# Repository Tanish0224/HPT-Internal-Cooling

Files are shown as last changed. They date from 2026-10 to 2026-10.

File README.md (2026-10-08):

# Cooled HPT Blade: Cooling Architecture and CAD

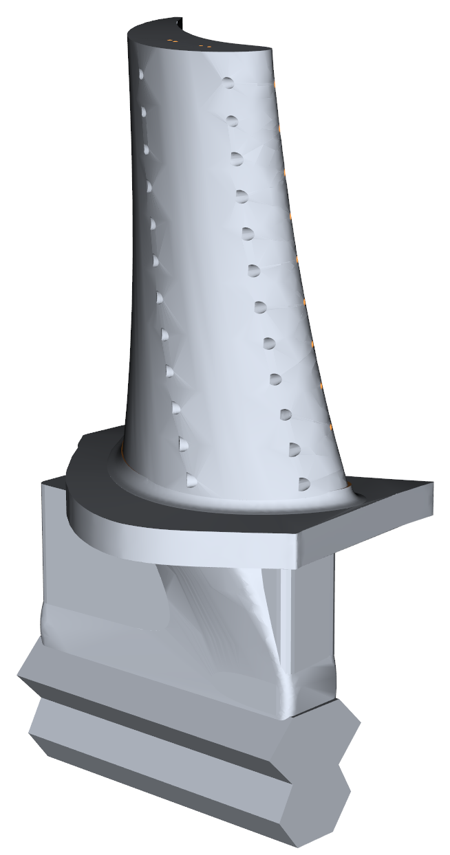
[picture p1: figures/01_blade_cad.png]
Current HPT blade CAD


A high-pressure-turbine (HPT) rotor blade with a two-circuit internal cooling system and film cooling, modelled as a
single CAD solid (66-blade stage, 45 mm span). The repository contains the current CAD model together with its design
basis, the reasoning behind the cooling architecture, and a review of the exported geometry. The project focuses on CAD
design and cooling-architecture development; no CFD, conjugate heat-transfer or structural analysis has been run on the
current CAD model.

## The engineering problem

The first rotor blade of an HPT sits in gas hotter than its nickel single-crystal alloy can tolerate. At the assumed
rotor-inlet condition the blade sees a relative total temperature of about 1,590 K, while the metal has to stay near
1,357 K locally and 1,226 K in bulk to reach a useful creep life. The gap is closed with compressor air routed through
the blade. That air does no work in the blade row and adds mixing loss where it re-enters the gas path, so the design
question is how to hold the metal limits with the least coolant, in a blade that can be cast and drilled.

## Design objective

Develop a turbine-blade CAD model that incorporates a practical cooling architecture: internal cooling to remove heat
from the wall, and film cooling to lower the temperature of the gas that drives heat into it, with coolant fed from the
root and discharged where its pressure suits the local external pressure.

## Cooling architecture

Two internal coolant circuits are fed separately at the root face and exit where their pressure suits them.

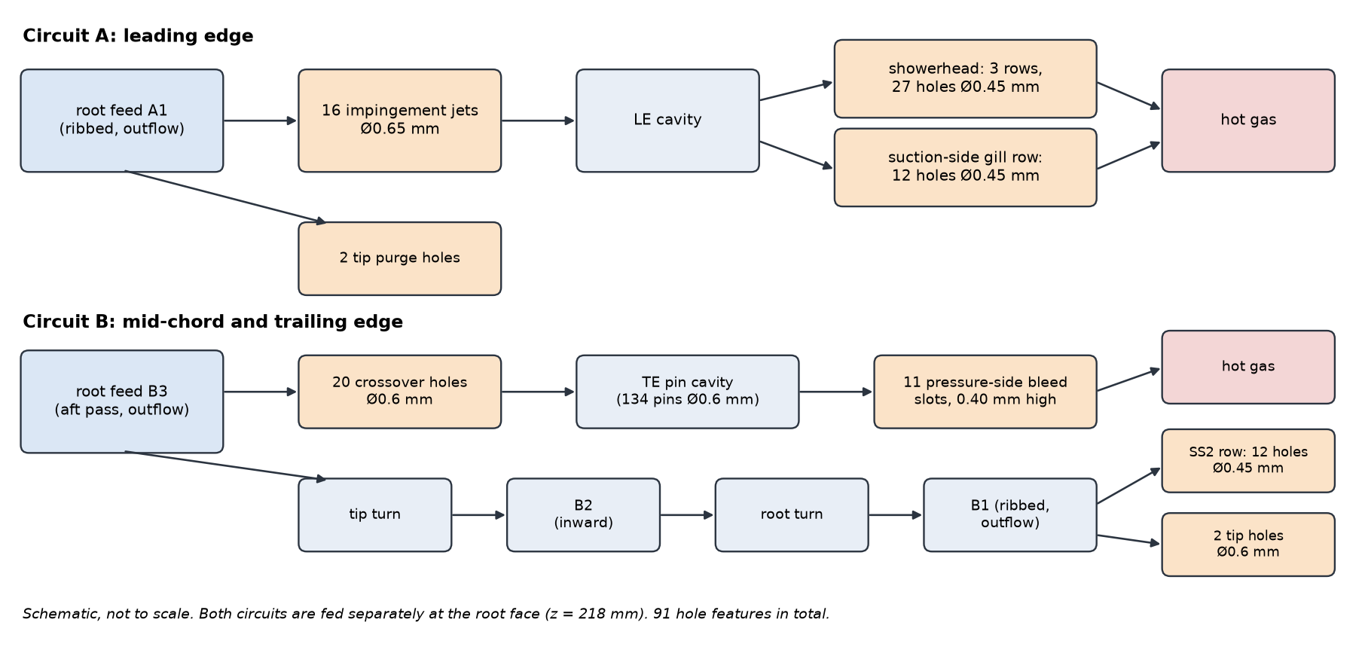
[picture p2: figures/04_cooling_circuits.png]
Coolant circuits


* **Circuit A, leading edge.** Root feed A1 supplies 16 impingement jets that strike the inside of the leading-edge
  cavity; the spent air leaves through three rows of showerhead holes and a suction-side film row.
* **Circuit B, mid-chord and trailing edge.** The aft passage B3 feeds the trailing-edge pin cavity, which discharges
  through 11 pressure-side bleed slots. The rest of the flow runs a three-pass ribbed serpentine (B3, B2, B1) and leaves
  through a second suction-side film row and tip holes.

The model contains 91 hole features (16 impingement jets, 20 trailing-edge crossover holes, 27 showerhead holes, 12 + 12
suction-side film holes and 4 tip holes), 70 rib segments, 134 trailing-edge pins and 11 discharge slots.

## Design basis

The geometry was developed from an assumed stage operating point anchored to published GE test-engine data. Values taken
from the published reference are separated from project assumptions in the status column.

| | Value | Status |
|---|---|---|
| Rotor-inlet gas | 1,700 K, 3.0 MPa; nozzle exit 600 m/s at 68° | ASSUMED, anchored to the NASA/GE Energy Efficient Engine HPT (rotor inlet 1,694 K) |
| Blade speed | 350 m/s at 275 mm mean radius (12,154 rpm) | ASSUMED |
| Stage | 66 blades, span 45 mm (252.5–297.5 mm radius), exit swirl −20° | Reaction 0.20 hub, 0.32 mean |
| Sections | thickness/chord 0.21 hub, 0.19 mean, 0.17 tip; leading-edge radius 1.8 mm | Sized to fit six cavities |
| Coolant at the root | 879 K, 2.95 MPa; target about 3 % of core flow | CALCULATED from the reference engine's cooling source, with an assumed supply loss |
| Metal limits | 1,357 K local, 1,226 K bulk | ASSUMED, anchored to the reference engine's coating and pitch-line temperatures |
| Walls | 1.0 mm skin, 0.9 mm webs, 0.75 mm trailing-edge lip | DECISION; no manufacturing source (see [limitations](LIMITATIONS.md)) |

Details, sources and the decision list are in [`design/`](design/README.md).

## Why the main features exist

| Feature | Reason |
|---|---|
| Two circuits fed from the root | The showerhead exits at near-stagnation pressure and the trailing edge at the lowest, so each circuit has its own supply. The two-circuit design has a showerhead back-flow margin of 0.11 (CALCULATED, 94-hole model); a shared-supply case was not calculated |
| Impingement jets in the leading edge | Highest external heat transfer is at the stagnation region; the jets give the nose its internal cooling |
| Three-pass ribbed serpentine | A two-pass layout with large passages warmed the coolant only 60–80 K; smaller passages and three passes raised the exit temperature to about 970 K at about 3 % flow |
| Trailing edge fed from the first pass | The coolest air goes to the thinnest, hardest-to-cool region, as in the reference engine |
| Pin cavity and 11 bleed slots | The thin trailing edge needs pins for conduction and heat transfer; the slot count follows the reference engine |
| Two suction-side film rows, no pressure-side row | The model put the peak metal temperature on the mid suction side; a pressure-side row over-cooled that surface and starved the serpentine |
| Film holes not smaller than 0.45 mm | The optimiser drove holes to 0.35 mm; the reference design used 0.51 mm and notes that small holes plug |
| Flared shank | Puts the airfoil walls over the shank instead of loading the platform in bending (earlier-geometry screening FEA: hub-band peak von Mises 942 → 593 MPa) |

*Rows that quote model outcomes (coolant warm-up, over-cooling, hole size) come from the project's coupled model on an earlier geometry; those data are not published, and [figure 05](figures/05_design_iterations.png) shows the iteration chart.*

## Current CAD model

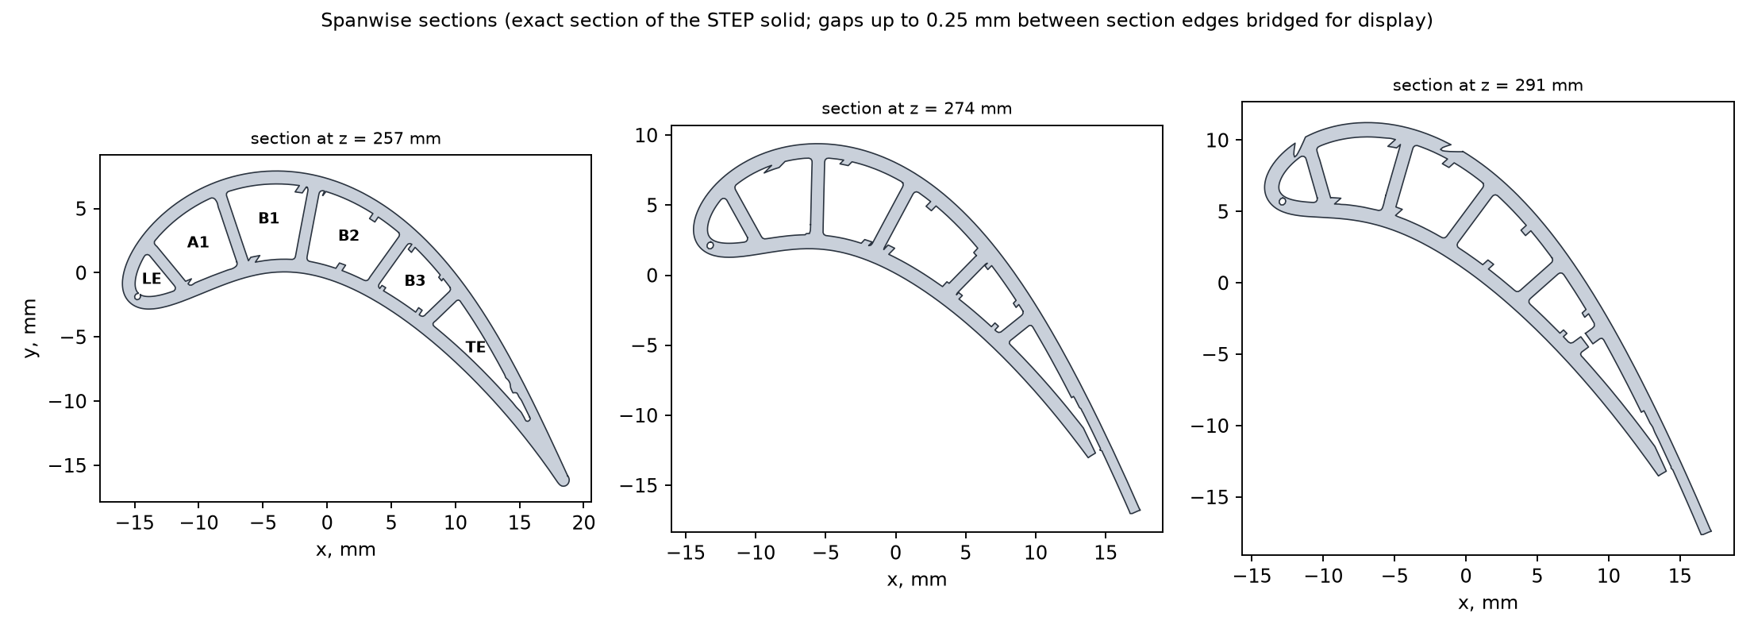
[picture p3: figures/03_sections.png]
Sections


*Sections of the exported solid (gaps up to 0.25 mm between section edges are bridged for display). At z = 257 mm the six
passages are labelled; at the higher stations the plane crosses hole and slot cuts, which open some passages to the outside.*

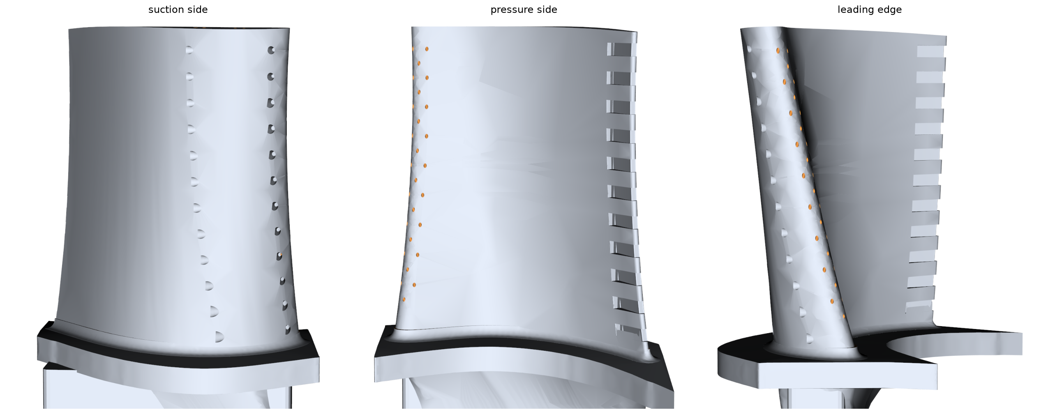
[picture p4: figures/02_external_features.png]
External features


The blade is one valid solid of 1,542 faces and 17,216.6 mm³, with the root face at z = 218 mm and the airfoil tip at
z = 297.5 mm. The cooling design file listed 94 holes; three were removed because their geometry was unsound (two showerhead
holes ended in a dead-end tail and the last trailing-edge crossover hole overlapped the tip turn), leaving the 91 above
([why](design/README.md#from-94-to-91-hole-features)). The CAD files, their identification hashes and the coordinate
system are described in [`cad/`](cad/README.md).

## Key results

The current CAD model is a single valid blade solid with 1,542 faces and 17,216.6 mm³ volume. All 91 cooling-hole openings and 11 trailing-edge discharge slots were confirmed on the exported geometry, with sampled wall thickness of at least 0.68 mm.
The design allocates 3.15% of core flow to coolant, and the project thermal model predicts a peak metal temperature of 1,317 K, 40 K below the assumed local limit; this is not a CFD result.

## Repository map

| | |
|---|---|
| [`design/`](design/README.md) | operating point, architecture, decisions and why, sensitivities, references |
| [`cad/`](cad/README.md) | the current CAD model (zipped STEP), structural derivative, identification, how to open it |
| [`verification/`](verification/README.md) | geometry review of the exported CAD, with recorded results |
| [`data/`](data/) | design data: section definition, design basis, cooling design |
| [`analysis_context/`](analysis_context/README.md) | 2-D RANS and FEA on earlier geometry; not validation of the current CAD |
| [`history/`](history/README.md) | the initial design and how the design evolved, briefly |
| [`scripts/`](scripts/README.md) | design-basis calculation, panel method and wall-thickness measurement |
| [`EVIDENCE_INDEX.md`](EVIDENCE_INDEX.md) | where each number comes from |
| [`figures/`](figures/README.md) | figures and their sources |

This repository has not undergone independent external review.

Project by **Tanish Shetty**. Tools: Python (NumPy) for design calculations, SolidWorks 2026
(import and volume comparison), ANSYS Fluent 2025 R1 and ANSYS MAPDL 2025 R1 (earlier geometry only). Code is MIT-licensed; CAD and figures
are covered by [`ASSET_NOTICE.md`](ASSET_NOTICE.md).

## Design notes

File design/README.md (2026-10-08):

# Design basis and cooling architecture

Labels used throughout (**SIMULATION**: CFD or FEA, earlier geometry only; results marked "model output, not published" come from the project model, whose data are not in this repository): **SOURCED** (taken from a cited public document), **ASSUMED** (a project assumption),
**CALCULATED** (derived by the project's models), **DECISION** (a design choice), **VERIFIED** (measured on the CAD).

## The thermal problem

The first rotor blade of a high-pressure turbine sits in gas hotter than its nickel single-crystal alloy can tolerate.
At the assumed rotor-inlet condition the blade sees a relative total temperature of about 1,590 K, while the metal has
to stay near 1,357 K locally and 1,226 K in bulk to reach a useful creep life. The gap is closed with air taken
from the compressor and routed through the blade. That air is not free: it bypasses the combustor, does no work in
the blade row and adds mixing loss where it re-enters the gas path. The design question is how to hold the metal limits
with the least coolant, in a blade that can be cast and drilled.

Internal cooling (impingement, ribbed passages, pins) removes heat from the wall; film cooling lowers the temperature of
the gas that drives heat into it. Neither is sufficient alone where the external heat load is highest, and the
pressure that drives the coolant out must exceed the local external pressure with margin at every exit.

## Operating point and blade basis

| Quantity | Value | Status |
|---|---|---|
| Rotor-inlet T01, P01 | 1,700 K, 3.0 MPa | ASSUMED; reference engine rotor-inlet design 1,421 °C = 1,694 K, compressor delivery 2.66–3.08 MPa (SOURCED, [G1](REFERENCES.md)) |
| Nozzle exit | 600 m/s at 68° | ASSUMED |
| Blade speed | 350 m/s at the 275 mm mean radius (12,154 rpm) | ASSUMED |
| Annulus | radius 252.5–297.5 mm (span 45 mm) | retained from an earlier project stage |
| Rotor exit swirl | −20° | DECISION: hub reaction about 0.2 (0.196); mean reaction 0.32 (reference engine 0.34) |
| Core flow | 79.9 kg/s, 1.21 kg/s per blade passage | CALCULATED |
| Blades | 66 | DECISION; suction-side diffusion ratio 1.17–1.20 for 66–72 blades, Zweifel about 1.0 |
| Sections | thickness/chord 0.21 / 0.19 / 0.17 (hub / mean / tip), leading-edge radius 1.8 mm | DECISION, the smallest values that hold six cavities with 1.0 mm walls and 0.9 mm webs |
| Chord | 38.9 / 38.6 / 41.5 mm | CALCULATED from the section definition ([`../data/blade_sections.json`](../data/blade_sections.json)) |
| Stacking lean | 1.06 mm axial, 2.22 mm tangential at the tip | CALCULATED; cancels design-point gas bending (hub bending stress 102 → about 0 MPa) |
| Coolant at the root | 879 K, 2.95 MPa | CALCULATED from the reference engine's cooling-air source (593 °C), an assumed inducer radius of 0.15 m and a 5 % supply loss |
| Coolant target | about 3 % of core flow | ASSUMED, within the reference blade's 2.25–3.3 % |
| Metal limits | 1,357 K local, 1,226 K bulk | ANCHORED to the reference blade's coating maximum (1,084 °C) and pitch-line bulk temperature (953 °C) |
| Alloy | CMSX-4-class single crystal, ⟨001⟩ radial | DECISION; properties ASSUMED |

Velocity triangles (free vortex, constant axial velocity 225 m/s):

| | exit angle β3 | turning | ψ = Δh/U² | reaction | M3,rel |
|---|---|---|---|---|---|
| hub | −61.3° | 113.0° | 2.16 | 0.20 | 0.63 |
| mean | −62.5° | 105.1° | 1.82 | 0.32 | 0.65 |
| tip | −63.7° | 94.8° | 1.56 | 0.42 | 0.68 |

The stage is more highly loaded than the reference engine (tip speed 379 m/s against 514 m/s), which is ASSUMED to lie
within high-work HPT practice; centrifugal stresses are correspondingly lower than an engine-scale rotor would see.

## Cooling architecture

Two circuits are fed separately at the root face (z = 218 mm). Each exits where its pressure suits it.

| Family | Count | Diameter / size | Fed by | Role |
|---|---|---|---|---|
| Leading-edge impingement jets | 16 | 0.65 mm | A1 | strike the inside of the leading-edge cavity (s/d = 4) |
| Showerhead | 27 (3 rows) | 0.45 mm, 30° radial | LE cavity | film over the stagnation region |
| Suction-side gill row | 12 | 0.45 mm, shaped, at 6.0 mm from stagnation | LE cavity | film on the accelerating suction side |
| Suction-side second row (SS2) | 12 | 0.45 mm, shaped, at 28 % camber | B1 | film where the model put the peak temperature |
| Trailing-edge crossover | 20 | 0.6 mm | B3 | feed the pin cavity |
| Tip holes | 4 | 2 × 0.45 mm (A1), 2 × 0.6 mm (B1) | A1, B1 | keep dead-ended passages flowing near the tip |
| **Hole features** | **91** | | | |
| Pressure-side bleed slots | 11 | 0.40 mm high, 1.78 mm open, 2.13 mm lands, cut-back at 88 % chord | pin cavity | trailing-edge exit |
| Trailing-edge pins | 134 | 0.6 mm, 1.4 mm pitch | | conduction and heat transfer in the thin trailing edge |
| Ribs | 70 segments | height 0.10 of the hydraulic diameter, pitch 10 × height | A1, B1, B2, B3 | raise internal heat transfer |

Walls are 1.0 mm, webs 0.9 mm, core fillets 0.25 mm and the trailing-edge suction-side lip 0.75 mm (DECISION).

* **Circuit A** (15.9 g/s, 94-hole design): A1 → 16 jets → leading-edge cavity → showerhead and gill row; two tip purge holes.
* **Circuit B** (22.7 g/s, 94-hole design): B3 → crossover holes → pin cavity → 11 bleed slots; B3 → tip turn → B2 → root turn →
  B1 → SS2 row and two tip holes.

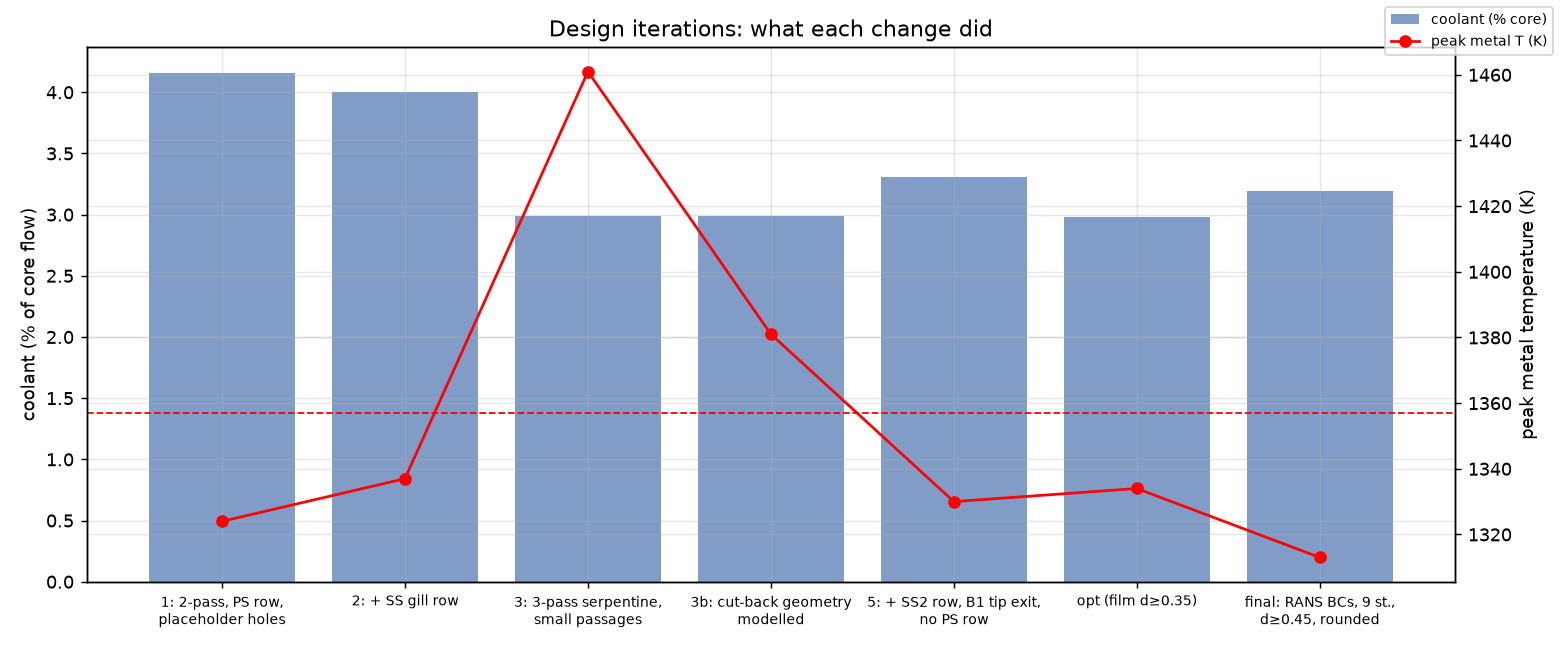
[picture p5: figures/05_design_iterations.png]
Design iterations


*How the architecture came out of the model (CALCULATED, earlier-geometry model): each change and what it did to coolant
fraction and peak metal temperature.*

| Iteration | Change | Coolant | Peak metal | Lesson |
|---|---|---|---|---|
| 1 | two-pass serpentine, pressure-side row, placeholder holes | 4.16 % | 1,324 K | over-cooled; coolant heated only 60–80 K |
| 2 | + suction-side gill row | 4.00 % | 1,337 K | more exit area raised circuit-A flow, not cooling |
| 3 | three-pass serpentine, smaller passages | 2.99 % | 1,461 K | coolant used well; the trailing-edge hot spot was a modelling error |
| 3b | pressure-side cut-back modelled geometrically | 2.99 % | 1,381 K | hot band on the mid suction side over B1 |
| 5 | + SS2 row, B1 tip exit, no pressure-side row | 3.31 % | 1,330 K | pressure side needed no film |
| opt | 15-variable constrained optimisation | 2.98 % | 1,334 K | optimiser pushed holes to 0.35 mm |
| final | external boundary conditions from RANS, holes ≥ 0.45 mm, rounded | 3.19 % | 1,312 K | the chart shows the 1,313 K of the run before the last rounding |

## Coupled model results (CALCULATED, not CFD on this geometry)

The model is a 2-D finite-volume conduction solution in the real metal section at nine radii, coupled to a 1-D coolant
network per circuit (supply pressure, inlet loss, rotation, rib friction, turns, orifices to the local static pressure)
and to a film-effectiveness correlation. External boundary conditions come from 2-D RANS at hub, mean and tip on the
earlier geometry ([`analysis_context/`](../analysis_context/README.md)).

| | Designed, 94 hole features | project model, 91 hole features (as modelled in the current CAD) |
|---|---|---|
| Coolant per blade | 38.6 g/s = 3.19 % of core flow | 38.1 g/s = 3.15 % |
| Peak metal temperature | 1,312 K (suction side near the tip) | 1,317 K |
| Mean section bulk temperature | 1,147 K | 1,151 K |
| Minimum showerhead back-flow margin | 0.112 | not recomputed |

Uncertainty (94-hole model; peak metal temperature, nominal 1,312 K):

| Perturbation | Change |
|---|---|
| film effectiveness −30 % | +46 K |
| cut-back effectiveness 0.7 → 0.5 | +47 K |
| internal heat transfer −20 % | +6 K |
| metal conductivity −15 % / +15 % | +3 / −2 K |
| leading-edge impingement −30 % | −1 K |

The nominal design holds 45 K margin to the local limit; either film uncertainty alone exceeds it (film −30 % gives 1,358 K against the 1,357 K limit). Film behaviour is
therefore the first thing a simulation of the current design should resolve. Raw numbers: [`sensitivity/`](sensitivity/).

## From 94 to 91 hole features

The original design file listed 94 holes. A geometric review of the hole geometry against the cavities found three that were not sound; they were removed from the CAD before the current model was finalised:

| Removed | Geometry problem | Evidence |
|---|---|---|
| showerhead holes #0 and #19 | the 30° radial inclination put the hole's inner end about 3.4 mm hub-ward of the exit, below the leading-edge cavity floor, leaving a 0.8 mm dead-end tail | position of the hole's inner end against the cavity floor |
| trailing-edge crossover #20 | the last station (z = 295 mm) lies inside the tip turn and overlapped it | position of the last station against the tip turn |

Thermal effect, bounded by the model with a smeared hole density: removing the two showerhead holes gives +5.5 K peak
metal temperature and −0.3 g/s coolant; removing the crossover hole gives 0 K and −0.2 g/s (together +5.5 K and −0.5 g/s). This is an analysis
assumption and has not been checked by simulation of the current design.

## Assumptions that carry manufacturing risk

1. The 0.75 mm trailing-edge lip and the 0.40 mm slot need an advanced thin-wall casting process or core-wall control;
   a thicker lip was rejected because it thins the pressure-side wall over the slot (lip thickness 0.75 / 0.80 / 0.85 mm
   changes peak metal temperature by about 0.5 K, [`sensitivity/`](sensitivity/)).
2. Skin and web walls of 0.85–1.0 mm are within what conventional casting is described to reach (above about 0.76 mm,
   US 6,255,000); the thinner values are not.
3. 0.45 mm holes are drilled or EDM-formed after casting.
4. No manufacturer capability, tolerance or yield has been established.

## Files

* [`decisions.md`](decisions.md): the main design decisions and the reason for each.
* [`REFERENCES.md`](REFERENCES.md): sources.
* [`sensitivity/`](sensitivity/): hole-removal, lip-thickness and film/internal-heat-transfer sensitivities.
* [`../data/`](../data/): the design data behind the CAD: `blade_sections.json` (section definition), `design_basis.json` (operating point, velocity triangles, limits) and `cooling_design.json` (passages, hole rows, ribs, pins and slots).

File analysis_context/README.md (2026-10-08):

# Analysis context: 2-D RANS and screening FEA on earlier geometry

> **Earlier geometry. Not validation of the current design.**
> Everything in this folder was run on the second-design blade, not on the current design, and the results are not attached to the current design.
> The current-design CAD has had no CFD, conjugate heat-transfer or structural analysis.

These analyses explain where the design inputs came from: the external boundary conditions of the cooling model and the
structural reasoning behind the shank shape. They are included so the design can be traced, not as evidence for the final CAD.

## 2-D blade-to-blade RANS (external flow)

* **Set-up.** ANSYS Fluent 2025 R1, compressible, k-ω SST, ideal gas (γ = 1.3), periodic blade-to-blade domain at hub, mean
  and tip, y⁺ about 1.3 (maximum 2.0), about 41,000 cells per section. Adiabatic-wall temperature from one run, heat-transfer
  coefficient from an isothermal run (h = q / (T_aw − 1,250 K)).
* **Purpose.** Surface pressure and external heat-transfer distributions as boundary conditions for the cooling model, and a
  check of the panel-method loading used to shape the airfoil.
* **Defect found and corrected.** The first runs used the solver's default energy equation, which omitted viscous dissipation,
  pressure work and kinetic energy; the adiabatic wall then recovered only about 30 % of the dynamic temperature. All runs were
  repeated with the full energy equation, after which the adiabatic-wall temperature matched the analytical recovery
  temperature within a few kelvin.

| | exit angle RANS / design | exit Mach RANS / design | loss Y |
|---|---|---|---|
| hub | −60.7° / −61.3° | 0.612 / 0.626 | 0.050 |
| mean | −62.3° / −62.5° | 0.639 / 0.651 | 0.043 |
| tip | −63.6° / −63.7° | 0.666 / 0.678 | 0.039 |

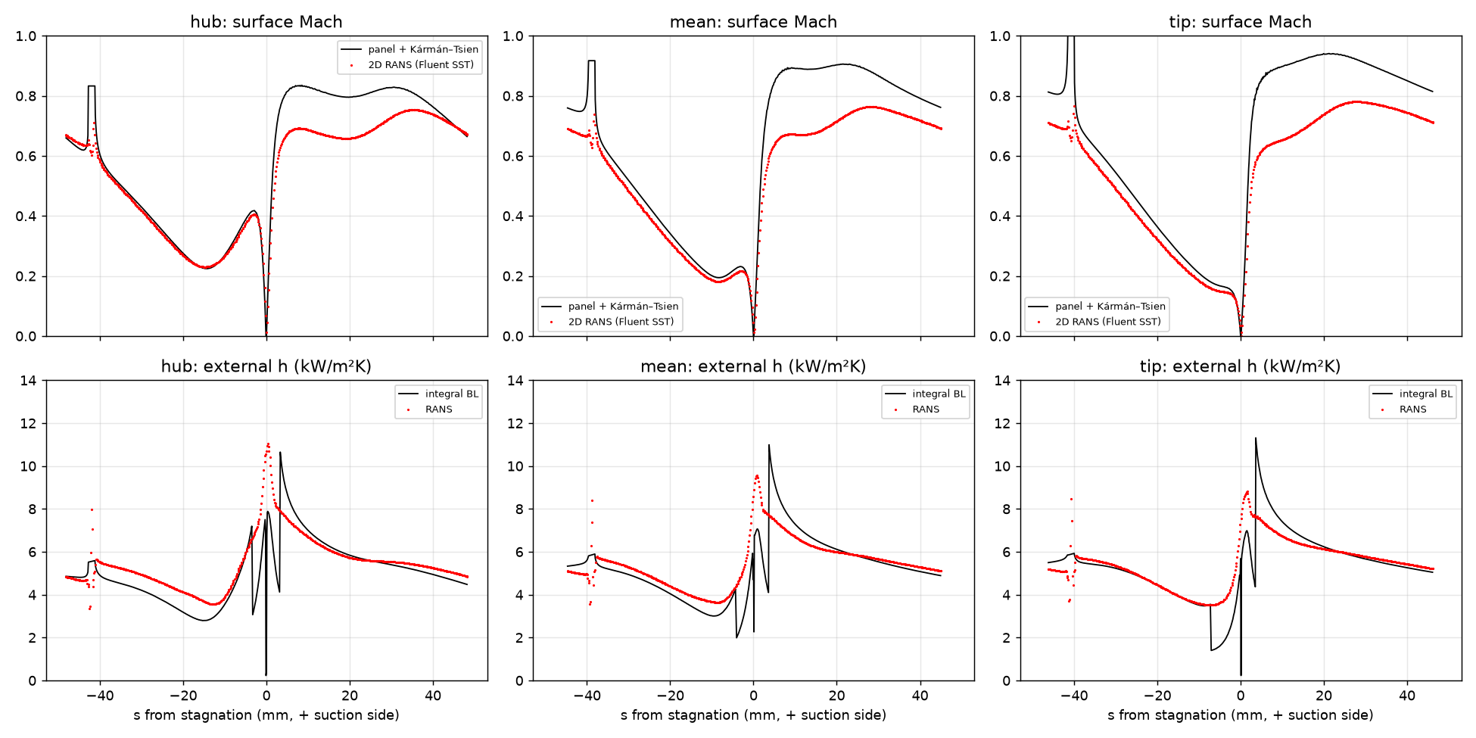
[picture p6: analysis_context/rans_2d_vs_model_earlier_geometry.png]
RANS against the panel and integral models


The panel method predicts the exit angle within 0.6° and overpredicts suction-side peak Mach: RANS peaks at 0.75 / 0.76 / 0.78 (hub / mean / tip; maxima of the stored `M_cfd` data), the panel curves in the figure at about 0.83 / 0.91 / 0.94 (read from the plot; the panel values are not stored in this repository). Section-averaged
external h agrees within 2 % on the suction side between RANS and an integral boundary-layer model; RANS is 9–19 % higher on the
pressure side and at the stagnation point (9.5 against 7 kW/m²K for the mean section). The design uses the RANS distributions, the more
conservative of the two. Data: [`rans_2d/`](rans_2d/).

Limits: two-dimensional, no tip gap, endwall or film-hole flow, no conjugate heat transfer, one turbulence model, no mesh study reported.

## Metal temperature (project model)

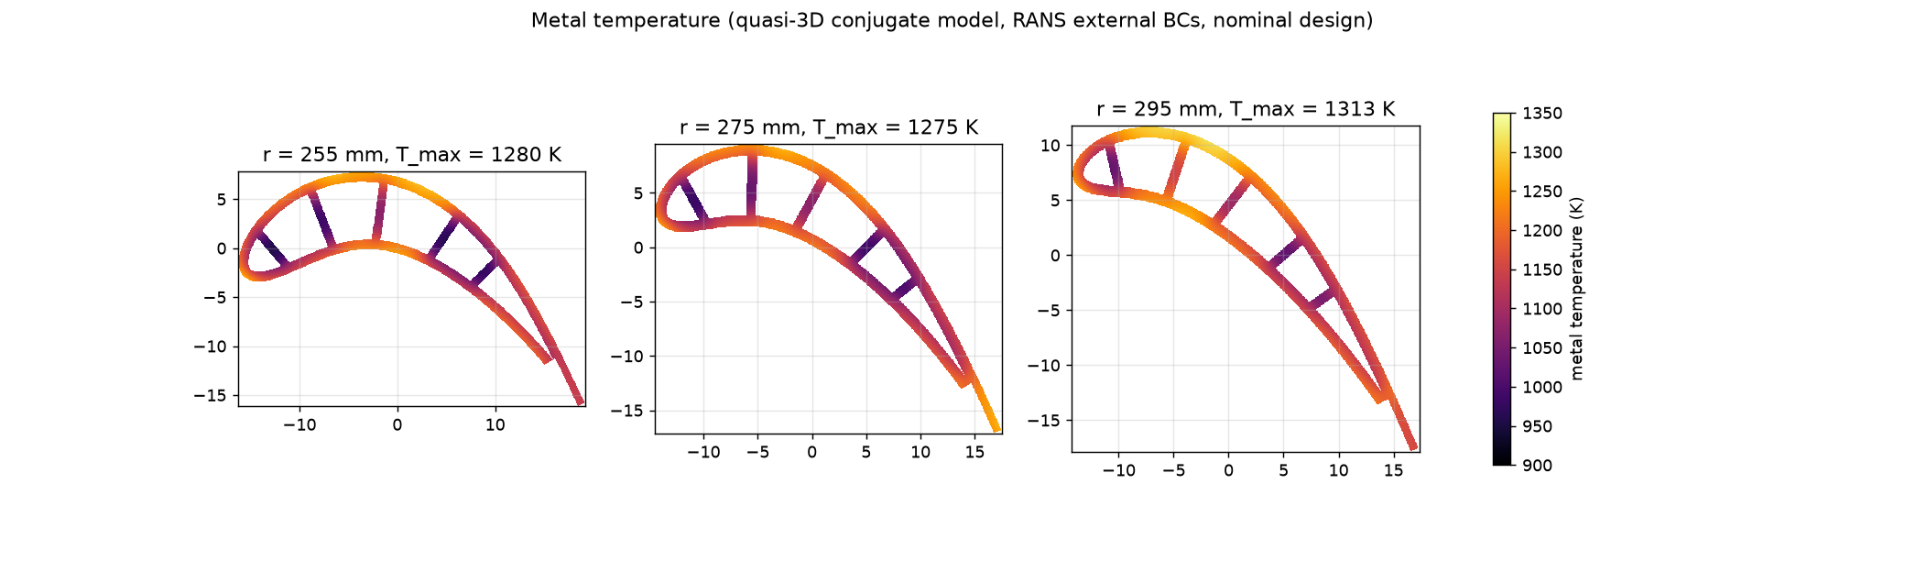
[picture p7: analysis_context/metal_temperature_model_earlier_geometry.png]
Metal temperature


*Quasi-3D conduction model with the RANS boundary conditions, nominal earlier design. CALCULATED; not CFD. The model's later
values for the 91-hole design are in [`../design/README.md`](../design/README.md).*

## Screening structural FEA

* **Set-up.** ANSYS MAPDL 2025 R1 on a structural derivative of the second design body (passage network only: holes, ribs, pins and
  cut-back removed; their local effect is noted, not computed). Tetrahedral quadratic mesh (SOLID187), 0.6 mm elements in the airfoil
  and platform, about 372,000 nodes. Centrifugal load at 12,154 rpm plus design-point gas loads (771 N tangential, 363 N axial). The set-up values in this paragraph are recorded from the unpublished model files.
  The bottom 2 mm of the simplified root is restrained.
* **Material.** CMSX-4-class single crystal treated as isotropic ⟨001⟩ with temperature-dependent modulus and expansion (ASSUMED).
* **What it showed.** With a box shank the airfoil walls loaded the platform in bending. The flared shank of the second design lowered the
  hub-band stresses; peak von Mises in the r = 252.5–254 mm band fell from 942 to 593 MPa.

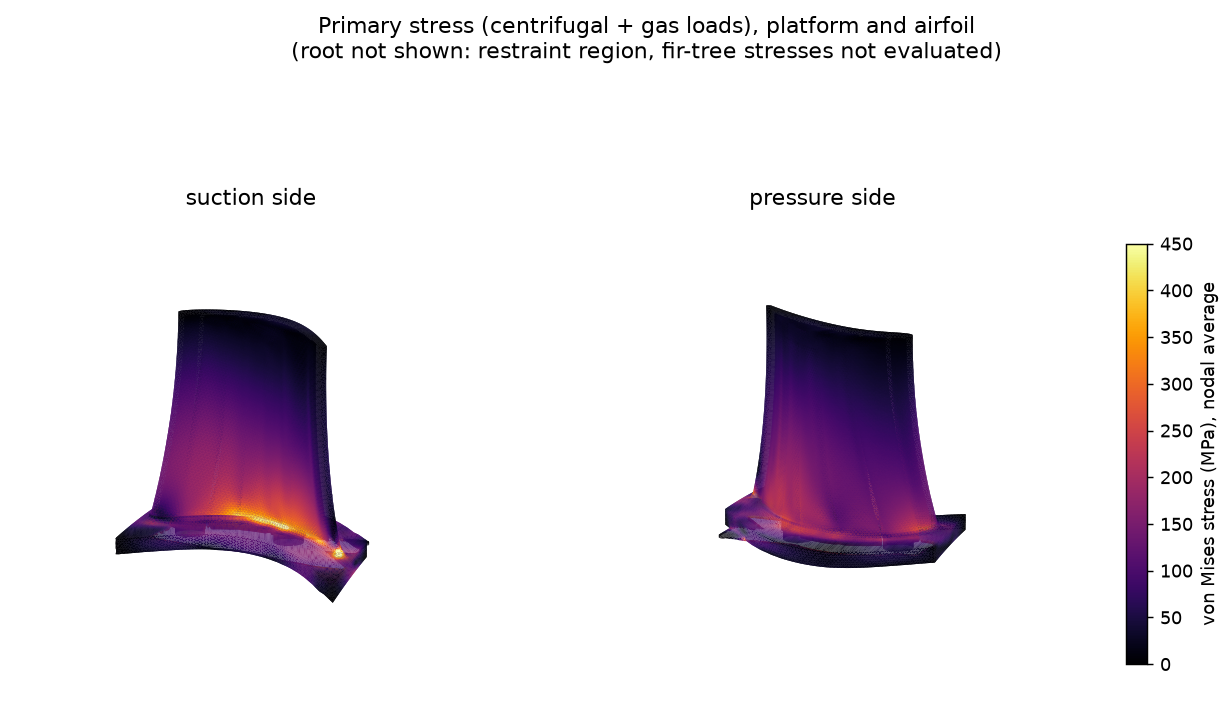
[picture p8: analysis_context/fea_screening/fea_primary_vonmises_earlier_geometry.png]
Primary stress, second design


| Band (radius, mm) | median von Mises, box shank → flared shank (MPa) | p99 (MPa) | peak (MPa) |
|---|---|---|---|
| 252.5–254 | 202 → 140 | 521 → 402 | 942 → 593 |
| 254–258 | 231 → 188 | 523 → 369 | 626 → 430 |
| 258–265 | 211 → 161 | 364 → 251 | 484 → 274 |

* **Creep.** On a conservative local elastic basis (local von Mises stress at local metal temperature), 0.26 % of the second design airfoil
  surface nodes have a rupture life below 300 h; the shortest, 46 h, is at r = 253.7 mm (1,250 K, 407 MPa). A section creep-rupture
  model with stress redistribution found no section life-limiting (predicted section lives of 4.9 × 10⁵ h and above, in the
  extrapolated range of the rupture curve, against the 300 h screening target). Local creep strain and thermo-mechanical fatigue at the hub mid-chord hot strip remain an open risk, because they need an
  anisotropic creep analysis.
* **Vibration.** First flap frequency of the second design: 1,133 Hz with the root base fixed and 1,560 Hz with the whole root fixed, so its
  position against engine orders depends on the attachment model.

Limits: no fir-tree contact, no fatigue, temperature-dependent moduli assumed, no stress at the root evaluated, holes and ribs
excluded, mesh convergence not shown. Data: [`fea_screening/`](fea_screening/).

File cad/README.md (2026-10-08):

# CAD

## What is authoritative

| | |
|---|---|
| **Current design** | the current CAD model for this project's scope: `GE_EEDP_P01_HPT_Blade_baseline.step.zip` |
| Current-design structural derivative | `GE_EEDP_P01_HPT_Blade_structural_derivative_for_FEA.step.zip`: outer body and passage network only (no holes, ribs, pins or cut-back); a convenience for structural meshing, derived from the current design. It has 3 shells: the outer surface and two enclosed voids, inferred to be the leading-edge and trailing-edge cavities, now reachable only through the removed holes. Its volume (17,219.1 mm³) is 2.6 mm³ above the baseline because the metal added by closing the holes and the cut-back slightly exceeds the rib and pin metal removed |
| Earlier designs | the previous design (same cooling architecture, faceted rib surfaces) is not published as a file; the initial design is kept for context in [`../history/`](../history/README.md) |

Identity, expected counts and SHA-256 values are in [`MANIFEST.json`](MANIFEST.json). `GE_EEDP_P01` in the file names is a project reference code; it does not indicate a GE part, drawing or data.

## Getting and using the file

The STEP files are zipped (88.6 MB → 23.8 MB for the baseline) to keep the repository small.

```
unzip cad/GE_EEDP_P01_HPT_Blade_baseline.step.zip
sha256sum cad/GE_EEDP_P01_HPT_Blade_baseline.step.zip   # compare with archive_sha256 in MANIFEST.json
```

Units are millimetres. The STEP is an AP214 file. It opens as one solid in SolidWorks 2026
(34.3.2). The coordinate system has **z along the span** (root face at z = 218.0 mm, airfoil
tip at 297.5 mm), x axial (leading edge towards −x) and y tangential. Both root feeds open on the root plane z = 218.0 mm.

`MANIFEST.json` lists the hashes, face counts, bounding box and volumes of both files, so the file can be identified and
compared in any CAD or STEP tool. It does not describe the cooling design; see [`../verification/`](../verification/README.md).

The geometry section of the STEP file (everything from the line `DATA;`) is identical to the file on which the geometry
review was carried out (DATA-section hash `40af25a5…`). The header and timestamp lines differ: the published file carries a
rewritten header, so its full-file hash differs from the hash recorded for the reviewed copy (`4c14c283…`). The geometry is the same.

## Model organisation

One solid containing:

* the **airfoil**: lofted outer surface through sections wrapped on cylinders about the engine axis, with a root fillet;
* the **platform** (hub flow-path face at 252.5 mm radius) and a **flared shank** under the hub airfoil;
* a **simplified root** below the shank, a prismatic stand-in for a fir-tree (not a contact geometry);
* **six cavities**, named by chordwise order: LE, A1, B1, B2, B3, TE; two **feed passages** from the root face
  (A1 and B3); a **tip turn** and a **root turn** connecting B3 → B2 → B1;
* **ribs** inside A1, B1, B2, B3 (70 segments), **pins** in the TE cavity (134), 91 **holes**, and 11 **bleed slots**
  through a cut-back at 88 % chord.

Face census: 1,542 faces: 926 planar, 296 cylindrical, 320 B-spline.

## Added platform edge

A periodic platform face carries one added edge (at x = 7 mm) so that SolidWorks reads the correct volume; the geometry is
unchanged. `_structural_derivative` in a file name marks the model without passage features.

## Known mesh-preparation issues

26 faces smaller than 0.001 mm² remain (20 at the trailing-edge bleed-slot ducts). Defeature at 0.01–0.02 mm before
meshing, and re-check the volume afterwards. The 0.40 mm slots and 0.45 mm holes need at least 4–6 cells across them
for a flow mesh.

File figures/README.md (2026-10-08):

# Figures

Curated figures only. Geometry figures are renderings of the published STEP; the circuit schematic is a drawing, not geometry.

| File | Shows | Source |
|---|---|---|
| `01_blade_cad.png` | whole blade, leading-edge / suction-side view; hole walls tinted orange | `cad/GE_EEDP_P01_HPT_Blade_baseline.step.zip` |
| `02_external_features.png` | suction side, pressure side (11 bleed slots, showerhead) and leading edge | same |
| `03_sections.png` | exact sections at z = 257.3, 274.4 and 291.2 mm; passages named at 257.3 mm; gaps up to 0.25 mm between section edges are bridged for display | same |
| `04_cooling_circuits.png` | coolant paths and hole counts of circuits A and B | drawn from the design counts |
| `05_design_iterations.png` | coolant fraction and peak metal temperature through the design iterations | project coupled model, earlier geometry (CALCULATED) |

Figures in [`../analysis_context/`](../analysis_context/README.md) and [`../history/initial_design/`](../history/initial_design/README.md)
show earlier geometry and are labelled as such.

Rendering uses a 0.03 mm chordal tolerance; small features such as hole entries are tessellated and may look faceted.

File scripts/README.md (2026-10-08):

# Scripts

Python 3.12 with the packages pinned in [`../requirements.txt`](../requirements.txt). These scripts are the design
calculations and the wall-thickness measurement. They read the design data in [`../data/`](../data/) or the published STEP
in [`../cad/`](../cad/). The CAD model itself is published as a file; it is not produced by anything in this folder.

| Script | Role |
|---|---|
| `design_basis.py` | operating point, gas and coolant conditions, velocity triangles at hub, mean and tip, material and design limits; writes `data/design_basis.json` (re-running it reproduces the stored values) |
| `cascade_panel.py` | linear-cascade potential-flow panel method (vortex sheet with the periodic Green's function) used to shape the blade loading |
| `wall_probe.py` | skin and web thickness sampled on the exported solid: `python scripts/wall_probe.py <unzipped STEP>`, about ten minutes |

## Not included

The software behind the other geometry-review results, the cooling model, the 2-D RANS and FEA set-ups and the optimisation
are not published; their results are in [`../verification/`](../verification/README.md), [`../design/`](../design/README.md)
and [`../analysis_context/`](../analysis_context/README.md).

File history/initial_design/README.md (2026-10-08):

# Initial design: the earlier blade

**Status: superseded, kept as history. Nothing from the initial design's geometry is used in the current design.**

## What it was

A SolidWorks part: an earlier blade shape with a platform and fir-tree root, plus two straight
manifold bores and 32 L-shaped passage legs branching from them (231 features, of which 65 are cut features; volume
29,653.63 mm³; SolidWorks `Check2` = 0; SHA-256 `676f2dc9…dd27702d`).

* [`GE_HPT_Blade_initial_design.SLDPRT`](GE_HPT_Blade_initial_design.SLDPRT)

## What was reported at the time (HISTORICAL)

An earlier version of this repository reported, from checks on that solid: 32 of 32 passages connected (by a
volume-deficit method), 2 manifold segments connected, minimum wall 1.750 mm against a 1.5 mm requirement, smallest
neighbouring-hole ligament 0.413 mm, and the same results after a save, close and reopen. Those are measurements of
the solid and they stand as such. They do not describe a cooling system.

## Why it was superseded

1. **The outer shape was wrong.** Measured thickness/chord (perpendicular to the chord) was 0.329, 0.317 and 0.309 at hub,
   mean and tip, against 0.185, 0.171 and 0.160 for the same camber line built as specified, which is 1.8 to 1.9 times as thick. The specified
   thickness law is 0.15; the larger intended values are the same law measured across the cambered shape. The leading edge was a wedge
   with a nose angle of 27–32° instead of a 1.8 mm radius.

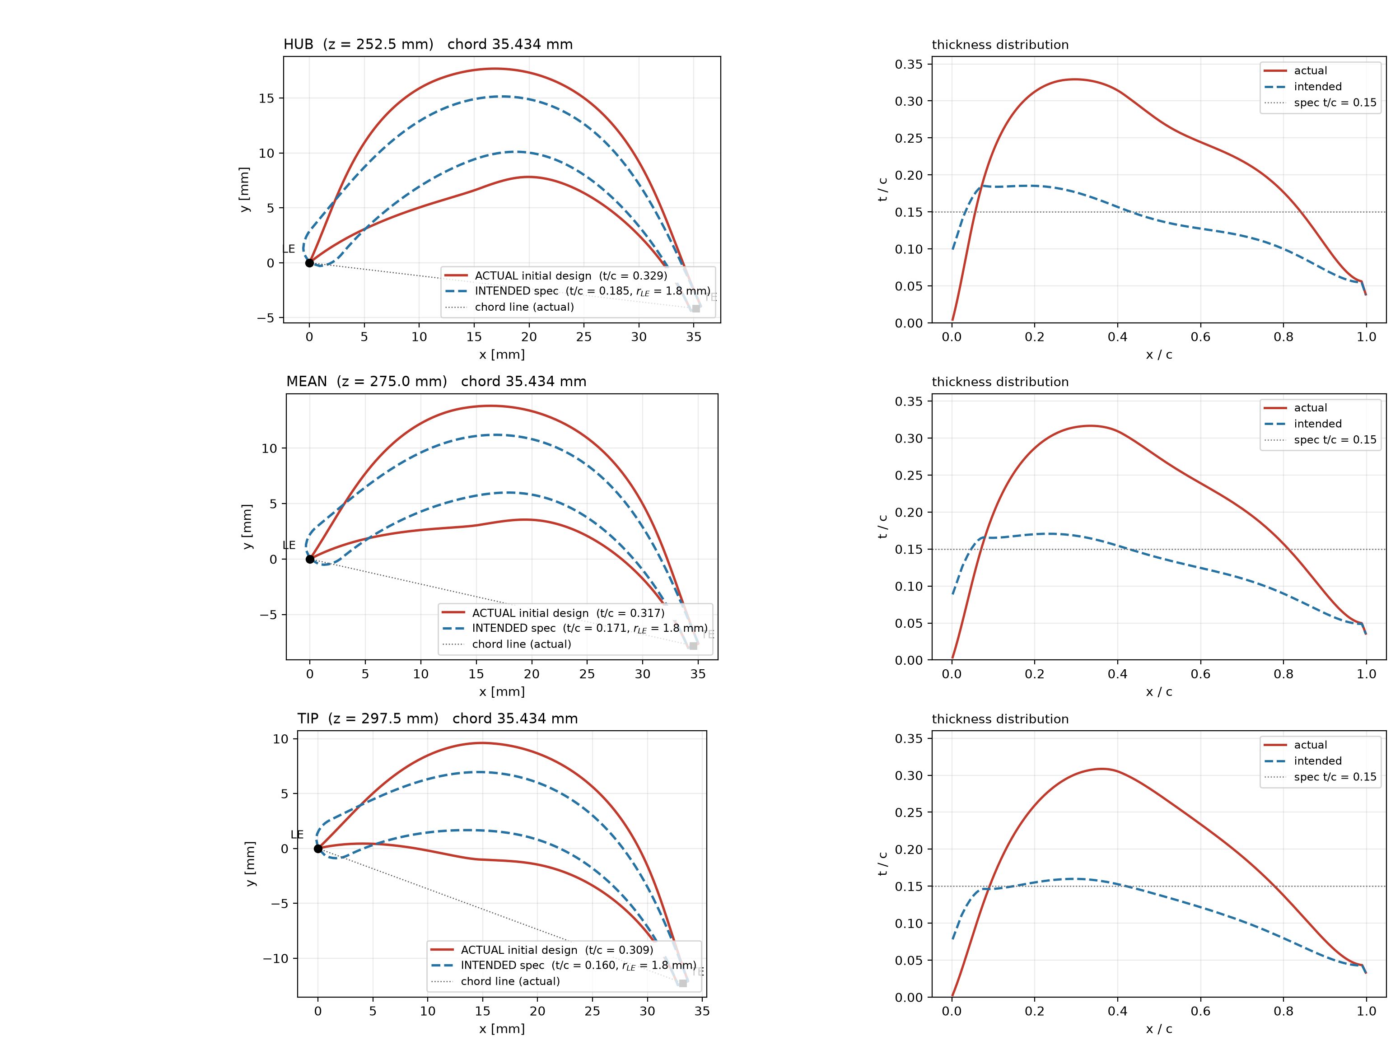
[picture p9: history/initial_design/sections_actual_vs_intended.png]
Sections
   

   *Actual (red) against the specified shape (blue) at hub, mean and tip; right: thickness distributions.*

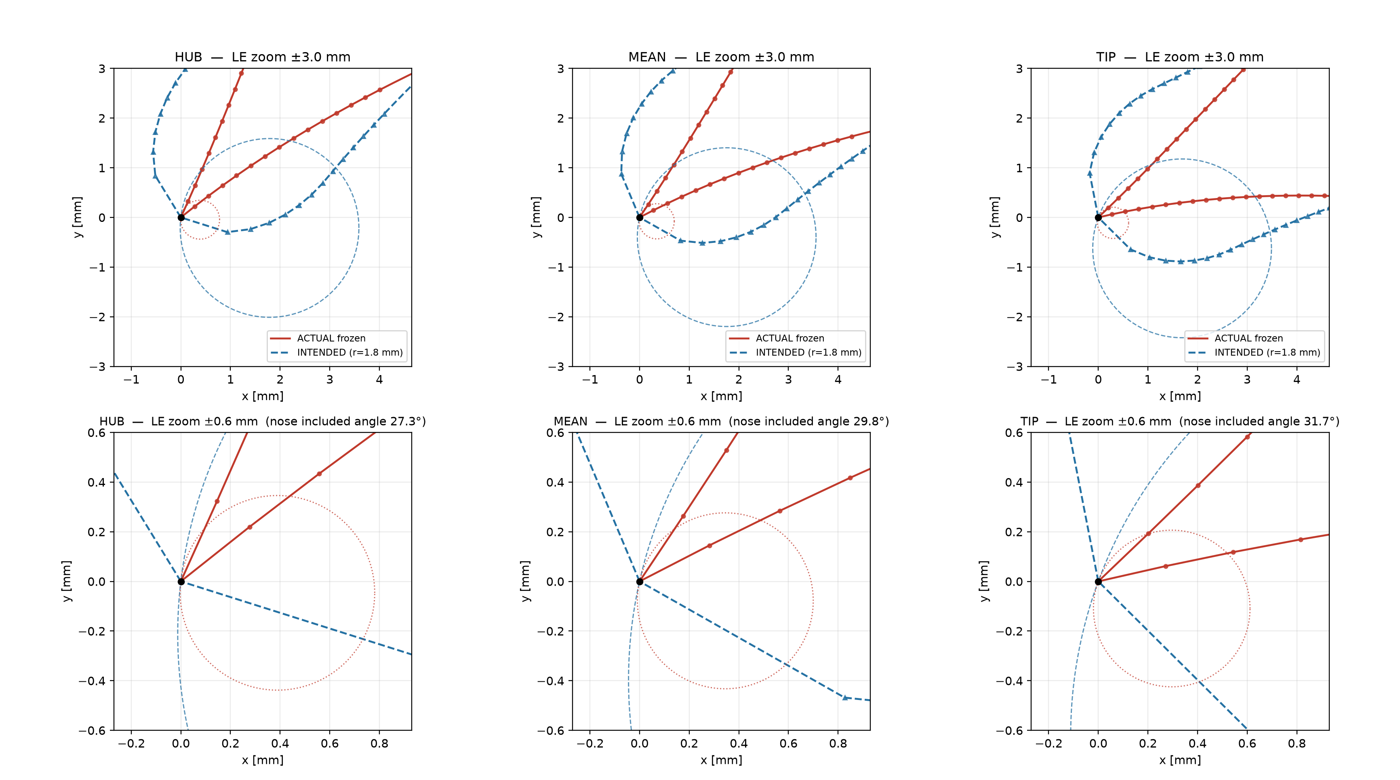
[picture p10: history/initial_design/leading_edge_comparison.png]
Leading edge
   

   Root cause, found by recomputing the section from its own definition: the thickness law returned the maximum thickness
   where a half thickness was expected, which doubles the thickness law exactly (0.30 against 0.15), and the leading-edge radius entered as the
   initial slope of a cubic, which cannot represent the square-root nose.
2. **The passages formed no circuit.** The two bores and 32 legs all ended blind in the metal: no root inlet, no exit,
   no leading-edge cavity, no film hole. No coolant could flow through the network as modelled.
3. **Some published statements were wrong and were corrected.** A "measured leading-edge radius of 0.39 → 0.31 mm" was an
   artefact of the circle-fit window, not a geometric radius; "the leading edge is 3–4 times more thermally severe" rested
   on the same defect; the minimum wall 1.775 mm was a 2-D section value and the solid measures 1.750 mm.

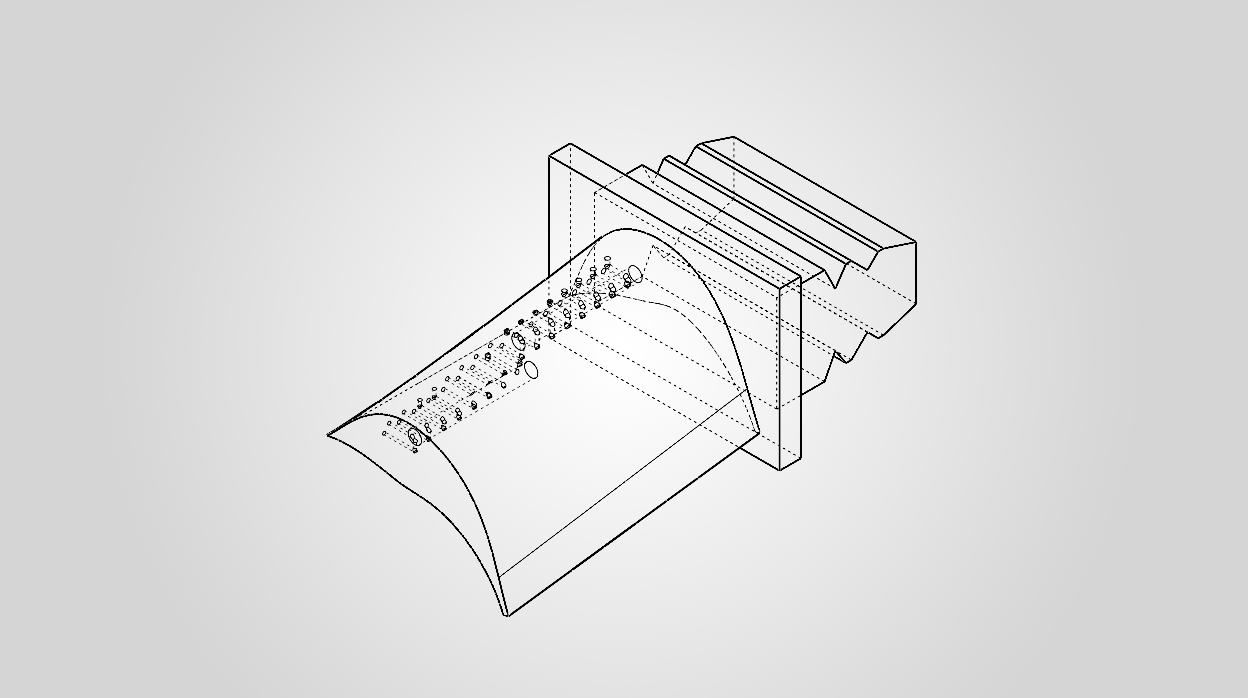
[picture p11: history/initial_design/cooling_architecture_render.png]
Initial design cooling network render


*Hidden-line view of the initial design's passage network. Historical geometry; not the current design.*

## What it taught

Verify the shape a cooling layout sits in before building the layout, and define the flow circuit (inlet, passages,
exits) before counting passages. Both shaped the redesign described in [`../README.md`](../README.md).

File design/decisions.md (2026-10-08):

# Main design decisions

Each entry gives the decision, the reason, and its status. The numbers (ED-035 and so on) are the identifiers used in
the project records. The numbering is not contiguous: decisions without a public entry are omitted. Status labels are explained in [`README.md`](README.md).

| ID | Decision | Reason | Status |
|---|---|---|---|
| ED-035 | Start a new blade lineage (second design) from the velocity triangles; keep the initial design unchanged | The initial design's outer shape was wrong (thickness/chord about 0.31–0.33, wedge leading edge) and its passages formed no flow circuit; fixing either needed the other re-derived | DECISION |
| ED-036 | Keep the assumed operating point and anchor it to the NASA/GE Energy Efficient Engine HPT; coolant 879 K / 2.95 MPa at the root; metal limits 1,357 K local, 1,226 K bulk | The reference gives a public set of consistent temperatures, pressures and coolant fractions | ASSUMED, anchored to a source |
| ED-037 | Rotor exit swirl −20° | Hub reaction about 0.2 (0.196, hub still accelerating) and mean reaction 0.32 against 0.34 in the reference; tested between −15° and −30° and kept | DECISION |
| ED-038 | Airfoil from a camber line plus a √ξ thickness law, so the leading-edge radius is real | An earlier airfoil definition produced a wedge; the nose radius is now measured with a shrinking-window curvature fit and converges to the specified 1.8 mm (checked on the section definitions; not repeated on the final CAD) | DECISION |
| ED-039 | 66 blades; hub axial chord 35 mm; loading shaped by a panel-method optimisation | Diffusion ratio is insensitive to blade count between 66 and 72, so the smaller count minimises cooled surface; a 31 mm hub chord gave diffusion 1.27 and a pressure-side hump | CALCULATED (model output, not published); checked by 2-D RANS |
| ED-040 | Thickness and nose radius set by the cooling packaging, then checked aerodynamically | These are the smallest values that hold six cavities with 1.0 mm walls and 0.9 mm webs; RANS loss Y = 0.043 at mean | DECISION |
| ED-041 | Two root-fed circuits; trailing edge fed from the first, coolest pass of a three-pass serpentine | A two-pass serpentine with large passages warmed the coolant only 60–80 K; three smaller passes raised it to about 970 K at about 3 % flow; the reference engine feeds the trailing edge from the first pass | DECISION, quantified by the model |
| ED-042 | Film rows only where the model shows they pay: two suction-side rows, no pressure-side row | A pressure-side row from B1 over-cooled the pressure side and drained B1, leaving the suction side over B1 hot | CALCULATED |
| ED-043 | External boundary conditions from 2-D RANS | Adiabatic-wall temperature and heat-transfer coefficient from two runs per section; an integral boundary-layer model is the cross-check. A defect was found and fixed: the solver's default energy equation left out viscous dissipation, pressure work and kinetic energy, so the adiabatic wall recovered only about 30 % of the dynamic temperature; all runs were repeated | SIMULATION (earlier geometry) |
| ED-044 | Keep a single leading-edge impingement row although its jet Reynolds number (about 42,000) is above the correlation range | The leading edge is not the limiting location: a 30 % lower internal coefficient there changes peak metal temperature by 1 K | Stated limitation with sensitivity |
| ED-045 | Minimum film-hole diameter 0.45 mm | The unconstrained optimiser went to 0.35 mm; the reference used 0.51 mm and notes that small holes cost more, plug and raise stress; coolant rose from 2.98 % to 3.19 % | DECISION (manufacturability) |
| ED-046 | Linear stacking lean | Cancels design-point gas bending: hub bending stress 102 → about 0 MPa, peak hub fibre stress 273 → 171 MPa | CALCULATED (model output, not published) |
| ED-049 | Structural screening set-up: passage network kept, holes, ribs, pins and cut-back removed; tetrahedral quadratic mesh; centrifugal plus gas loads; a lofted 1.5 mm root fillet | Without the fillet the airfoil-platform junction was a re-entrant stress singularity; the local effects of removed features are noted, not computed | DECISION; results in [`../analysis_context/`](../analysis_context/README.md) |
| ED-050 | Flared shank, closed root-turn shape, 0.5 mm shank margin; life basis of at least 300 h rupture at the design point | Puts the airfoil walls over the shank (earlier-geometry screening FEA, box shank to flared shank: median von Mises 231 → 188 MPa in the 254–258 mm band, hub-band peak 942 → 593 MPa); the reference blade's life table shows about 250 h at maximum take-off consuming its whole life, so a design-point screen of 18,000 h would be the wrong test | DECISION; SOURCED + ASSUMED |
| ED-051 | Keep the serpentine direction; creep-matched cooling tried and not adopted | Reversing circuit B would cool the hub mid-chord wall about 100 K (model estimate, not published) but starve the trailing edge; the reference engine makes the same choice. Remaining risk: local creep strain and fatigue on the hub mid-chord wall | DECISION; open risk stated |
| ED-055 | Trailing-edge exit as an explicit cut-back channel; slot height 0.40 mm | With 1.0 mm walls the pin cavity pinched to zero height before the cut-back, so the slot was not connected in the CAD; 0.28 mm is below a plausible ceramic-core thickness. Same metering area as the 0.28 mm slot at 65 % open (0.28 × 0.65 = 0.40 × 0.455 mm) | DECISION; 0.40 mm ASSUMED |
| ED-056 | Film-row inlets checked against their supply cavity; suction-side gill row moved to 6.0 mm | An early layout had holes whose inlets lay in solid metal, which a volume comparison alone did not reveal; with the row at 6.0 mm all 12 holes are feasible | DECISION |
| ED-057, 058 | Corrections to an earlier model: trailing-edge core fillet reduced so the 0.40 mm channel survives; a straight neck added to the flared shank where it pinched at the B3 feed; hole overshoot raised to 0.6 mm for a 45° hole; trailing-edge exit modelled as 11 separate bleed-slot ducts and confirmed on the exported solid | The earlier model had a blind trailing-edge exit, a feed slot 0.0 mm from the shank surface and one suction-side hole not through; the exit is now confirmed by point classification on the final solid | DECISION |
| (hole set) | Drop three hole features (94 → 91) | See [`README.md`](README.md#from-94-to-91-hole-features) | DECISION; geometric reasoning CALCULATED, resulting solid measured |
| (rib surfaces) | Smooth rib surfaces with spline sides | Ribs modelled as 80-vertex polygons gave about 80 faces each; smooth sides give 6 faces per rib and cut the whole model from 3,846 to 1,542 faces with the same holes, pins, slots and passages | DECISION; VERIFIED |

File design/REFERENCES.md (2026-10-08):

# References

Sources behind the design basis. "Checked" means the specific numbers quoted in this repository were compared with the
source text. Other entries are cited for the established finding stated; their numbers are not reproduced here.

## Reference engine and patents (numbers checked against the source)

| # | Source | Used for |
|---|---|---|
| G1 | Halila, E. E., Lenahan, D. T., Thomas, T. T. *Energy Efficient Engine High Pressure Turbine Test Hardware Detailed Design Report*, NASA CR-167955 (General Electric), 1982. NASA Technical Reports Server, record 19850002687 | Rotor-inlet design temperature 1,421 °C; compressor delivery pressure 2.66–3.08 MPa; rotor cooling-air source 593 °C; stage-1 blade coating maximum 1,084 °C and pitch-line bulk 953 °C; film holes 0.51 mm; trailing-edge cooling air exits through 11 pressure-side bleed slots; stage-1 blade design life 18,000 h and a life table (Table XX) with 264 h available, equivalent to 250 h at maximum take-off; stage-1 blade coolant 2.25–3.3 %; stage-1 tip speed 513.9 m/s and stage reaction 0.34; trailing-edge cooling air supplied from the first pass of a three-pass forward-flowing serpentine; small film holes described as more prone to plugging |
| P1 | US 5,296,308, *Investment casting using core with integral wall thickness control means*, Howmet Corp., 1994 | Cast walls of 0.018–0.055 in (0.457–1.40 mm) are practised with core protrusions of 0.020–0.045 in; the 0.457 mm screening floor |
| P2 | US 6,255,000, *Single-cast, high-temperature, thin wall structures*, Rolls-Royce / Allison, granted 2001 | States that cores thinner than 0.03 in (0.76 mm) were crushed or broken in conventional casting; the 0.76 mm indicator |

The patents are not manufacturing standards. Data files abbreviate the reference engine (Energy Efficient Engine, G1) as "E3".

## Method sources (cited for the finding stated)

| # | Source | Cited for |
|---|---|---|
| A1 | Han, J.-C., Dutta, S., Ekkad, S. *Gas Turbine Heat Transfer and Cooling Technology*, 2nd ed., CRC Press, 2012 | Cooled-blade layout: leading-edge impingement and showerhead, ribbed serpentine, pin fins, trailing-edge ejection; cast passages and drilled film holes |
| A5 | Dunn, M. G. "Convective Heat Transfer and Aerodynamics in Axial Flow Turbines." *J. Turbomachinery* 123(4), 2001 | External heat transfer: stagnation region, acceleration, transition |
| B1 | Horlock, J. H., Watson, D. T., Jones, T. V. "Limitations on Gas Turbine Performance Imposed by Large Turbine Cooling Flows." *J. Eng. Gas Turbines Power* 123(3), 2001 | Coolant flow erodes the benefit of higher inlet temperature |
| C1 | Pollock, T. M., Tin, S. "Nickel-Based Superalloys for Advanced Turbine Engines." *J. Propulsion and Power* 22(2), 2006 | Superalloy capability near a large fraction of melting point |
| D1 | Florschuetz, L. W., Truman, C. R., Metzger, D. E. "Streamwise Flow and Heat Transfer Distributions for Jet Array Impingement with Crossflow." *J. Heat Transfer* 103(2), 1981 | Impingement depends on jet spacing and standoff; crossflow degrades downstream jets |
| E1 | Bogard, D. G., Thole, K. A. "Gas Turbine Film Cooling." *J. Propulsion and Power* 22(2), 2006 | Film behaviour against blowing and momentum ratio; jet lift-off |
| G2 | Colban, W. F., Thole, K. A., Bogard, D. G. "A Film-Cooling Correlation for Shaped Holes on a Flat-Plate Surface." *J. Turbomachinery* 133(1), 2011 | Laterally averaged film effectiveness, used for all film rows; validity range 0.2 ≤ M ≤ 4, flat plate, 30° holes |
| G3 | Chupp, R. E., Helms, H. E., McFadden, P. W., Brown, T. R. "Evaluation of Internal Heat-Transfer Coefficients for Impingement-Cooled Turbine Airfoils." *J. Aircraft* 6, 1969 | Leading-edge impingement correlation (Re 3,000–15,000), used outside its range |
| G4 | Taslim, M. E. et al., ASME GT2002-30477 | Published leading-edge impingement data reach Re about 20,000 |
| G5 | Schneider, W., Hammer, J., Mughrabi, H. "Creep Deformation and Rupture Behaviour of the Monocrystalline Superalloy CMSX-4." *Superalloys 1992*, TMS | Larson–Miller rupture curve for creep screening |
| G7 | Mayle, R. E. "The Role of Laminar-Turbulent Transition in Gas Turbine Engines." *J. Turbomachinery* 113, 1991 | Transition onset in the integral boundary-layer cross-check |
| G8 | Kays, W. M., Crawford, M. E. *Convective Heat and Mass Transfer* | Integral external heat-transfer method used as the RANS cross-check |
| G9 | Metzger, D. E., Berry, R. A., Bronson, J. P. "Developing Heat Transfer in Rectangular Ducts with Staggered Arrays of Short Pin Fins." *J. Heat Transfer* 104, 1982 | Pin-fin array correlation form |

Bibliographic details were checked against publisher or index records when the list was compiled.

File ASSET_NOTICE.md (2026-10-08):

# Asset notice

The MIT License in [`LICENSE`](LICENSE) applies to the **source code** in this repository: the Python scripts in
[`scripts/`](scripts/).

It does **not** apply to the following, which are © 2026 Tanish Shetty, all rights reserved:

- CAD geometry (`cad/*.zip`, `history/initial_design/*.SLDPRT`);
- rendered images, schematics and figures (`figures/`, `analysis_context/*.png`, `history/**/*.png`);
- the recorded design, verification and analysis data files (`data/`, `design/sensitivity/`, `verification/results/`,
  `analysis_context/**/*.json`).

You may view and download these assets to evaluate and discuss this project. Please ask before reusing, modifying or
redistributing them.

The CAD is a study design. It is **not for manufacture**, and no part of this repository is certified or validated for
use in any real system. The reference engine data come from public NASA and patent documents cited in
[`design/REFERENCES.md`](design/REFERENCES.md); no third-party geometry, drawings or images are included.

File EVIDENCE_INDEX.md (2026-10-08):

# Evidence index

Where each number and claim in this repository comes from.

**Evidence classes**

| Class | Meaning |
|---|---|
| **VERIFIED** | measured on the exported current CAD model, with a recorded result file |
| **SIMULATION** | CFD or FEA result on earlier geometry (second design), never on the current design |
| **CALCULATED** | derived by the project's models or from the intended feature geometry; not CFD or FEA on the current design |
| **SOURCED** | taken from a public document cited in [`design/REFERENCES.md`](design/REFERENCES.md), compared with the source text |
| **ASSUMED / DECISION** | a project assumption or design choice |
| **HISTORICAL** | superseded geometry or an earlier statement, kept for the record |

"Result files" are in [`verification/results/`](verification/results/). Paths in them were rewritten to file names; see
[`verification/README.md`](verification/README.md).

## Design

| Claim | Class | Evidence |
|---|---|---|
| Reference-engine rotor inlet 1,421 °C, delivery pressure 2.66–3.08 MPa, cooling-air source 593 °C, coating maximum 1,084 °C, bulk 953 °C, film holes 0.51 mm, 11 pressure-side bleed slots, 18,000 h life | SOURCED | NASA CR-167955 ([`design/REFERENCES.md`](design/REFERENCES.md), G1) |
| Cast walls 0.018–0.055 in; cores under 0.03 in crushed in conventional casting | SOURCED | US 5,296,308; US 6,255,000 ([`design/REFERENCES.md`](design/REFERENCES.md)) |
| Operating point, blade speed, coolant supply, metal limits | ASSUMED, anchored to the above | [`design/README.md`](design/README.md), [`data/design_basis.json`](data/design_basis.json) |
| Section dimensions, 66 blades, velocity triangles | CALCULATED / DECISION | [`data/blade_sections.json`](data/blade_sections.json), [`data/design_basis.json`](data/design_basis.json), `scripts/design_basis.py` |
| Hole counts, diameters, slot height, wall and web values | DECISION | [`data/cooling_design.json`](data/cooling_design.json); the 91 intended holes in `connectivity_A_B0_C_F_G.json` (`design_check`); the removal of three of the original 94 holes is explained in [`design/README.md`](design/README.md#from-94-to-91-hole-features) |
| Coolant 38.1 g/s (3.15 %), peak metal 1,317 K, bulk 1,151 K, 91 holes | CALCULATED | [`design/sensitivity/hole_removal_sensitivity.json`](design/sensitivity/hole_removal_sensitivity.json) (`filtered_91holes`) |
| Coolant 38.6 g/s (3.19 %), peak metal 1,312 K, back-flow margin 0.112, 94 holes | CALCULATED | [`design/sensitivity/cooling_sensitivity.json`](design/sensitivity/cooling_sensitivity.json) (`nominal`) |
| Removing the showerhead holes: +5.5 K, −0.3 g/s; removing the crossover hole: 0 K, −0.2 g/s (together +5.5 K, −0.5 g/s) | CALCULATED | [`design/sensitivity/hole_removal_sensitivity.json`](design/sensitivity/hole_removal_sensitivity.json) (`bound_showerhead_only`, `bound_crossover_only`) |
| Film −30 % +46 K; cut-back 0.7 → 0.5 +47 K; internal h −20 % +6 K; conductivity +3 / −2 K; leading-edge h −30 % −1 K | CALCULATED | [`design/sensitivity/cooling_sensitivity.json`](design/sensitivity/cooling_sensitivity.json) |
| Trailing-edge lip 0.75 / 0.80 / 0.85 mm changes peak metal temperature by about 0.5 K | CALCULATED | [`design/sensitivity/lip_thickness_sensitivity.json`](design/sensitivity/lip_thickness_sensitivity.json) |
| Design iterations (coolant fraction and peak metal temperature) | CALCULATED (model output; only the chart is published) | [`figures/05_design_iterations.png`](figures/05_design_iterations.png); not regenerable from this repository |
| Reasons for each major decision | DECISION | [`design/decisions.md`](design/decisions.md) |

## Geometry and geometry review (current design)

| Claim | Class | Evidence | Method |
|---|---|---|---|
| One valid solid, 1,542 faces; 926 plane, 296 cylinder, 320 B-spline | VERIFIED | `check_summary.json` (S1), [`cad/MANIFEST.json`](cad/MANIFEST.json) | import of the exported file |
| Volume 17,216.6 mm³ (adaptive integration), 17,218.5 mm³ (SolidWorks 34.3.2) | VERIFIED | `volume_measurement.json`, `solidworks_import.json` | adaptive integration; SolidWorks `LoadFile2` |
| SolidWorks `Check2` = 2, not explained | VERIFIED (as a result) | `solidworks_import.json` | SolidWorks API |
| 91 holes, residual metal 0.0 mm³ in every hole | VERIFIED | `hole_residual_LE_TEcrossover_showerhead.json` (63), `hole_residual_SSrow_SS2row_tipholes.json` (28) | hole volume shrunk 10 %, intersected with the solid |
| 55 of 55 outlets (51 film holes, 4 tip holes) open to ambient | indication only | `film_breakout.json` | axis and end-point classification; not shown to reject a closed hole |
| 11 of 11 bleed-slot ducts open | VERIFIED | `te_exit_path.json` | 15 points per slot classified against the solid |
| 133 intended links; both feeds reach z = 218 mm; 49 isolation pairs without unintended overlap; hole spacing 0.72 mm and up | CALCULATED on the intended geometry, sampled on the solid | `connectivity_*.json`, `check_summary.json` (S2) | overlap volumes and sampled points |
| 10 passages, 300 sampled points each, none metal | VERIFIED | `passage_void_*.json` | point classification |
| Skin minimum 0.677 mm (TE), 0.91 mm (A1), 0.938 mm or more elsewhere; web minimum 0.848 mm | VERIFIED (sampled) | `wall_probe.json`, `check_summary.json` (S4) | extrema distance, 400 / 150 samples |
| 26 faces under 0.001 mm², 61 under 0.01 mm² | VERIFIED | `face_census.json` | face areas of the published file |
| 3,846 → 1,542 faces; B-spline faces 2,624 → 320; rib solid 82 → 6 faces | VERIFIED (previous design file not published) | [`cad/MANIFEST.json`](cad/MANIFEST.json) (hash of the previous design file); [`design/decisions.md`](design/decisions.md) | face counts of the previous and current design files |
| Geometry section of the published STEP identical to the reviewed copy | VERIFIED | [`cad/MANIFEST.json`](cad/MANIFEST.json) (`data_section_sha256`) | hash of the STEP text from `DATA;` |
| Wall-thickness measurement repeated on the published STEP | VERIFIED | `wall_probe.json`, `scripts/wall_probe.py` | the same sampled measurement run again on the published STEP gave identical values |
| The three removed holes and why | CALCULATED from the hole geometry; the solid then measured | [`design/README.md`](design/README.md#from-94-to-91-hole-features) | inner-end position against the cavity floor and tip turn |

## Earlier geometry (not the current design)

| Claim | Class | Evidence |
|---|---|---|
| 2-D RANS exit angle, exit Mach, loss Y at hub, mean, tip | SIMULATION, earlier geometry | [`analysis_context/rans_2d/cascade_performance.json`](analysis_context/rans_2d/cascade_performance.json) |
| Model against RANS external heat transfer | SIMULATION, earlier geometry | [`analysis_context/rans_2d/`](analysis_context/rans_2d/) |
| Screening FEA stresses, creep and modal frequencies, second design (box shank and flared shank) | SIMULATION, earlier geometry | [`analysis_context/fea_screening/`](analysis_context/fea_screening/) |
| Initial-design geometry (231 features, 65 cut features, 29,653.63 mm³), thickness/chord 0.309–0.329, wedge leading edge | HISTORICAL; read from the SolidWorks file and the earlier repository, not regenerable here | [`history/initial_design/`](history/initial_design/README.md) |

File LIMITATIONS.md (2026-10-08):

# Limitations

## Scope

1. **No simulation of the current design.** No CFD, conjugate heat-transfer (CHT) or structural analysis has been run on the current design
   geometry, and nothing here is validated by experiment. The current design is a CAD baseline prepared for such work, not a
   production blade.
2. **The operating point is assumed.** The gas state, blade speed and coolant supply are project assumptions anchored
   to a published test-engine design (NASA CR-167955); they are not data of any engine in service.
3. **No manufacturing qualification.** No manufacturer's capability, tolerance or yield was established.

## Model-derived numbers (CALCULATED)

4. **Temperatures, flows and margins are project-model values.** They come from a quasi-3D conduction model coupled to a
   one-dimensional coolant network, with external boundary conditions from 2-D RANS on earlier geometry. They were not
   computed on the current design and have no experimental check.
5. **Several correlations are used outside their range.** Leading-edge jet Reynolds number is about 42,000 against a
   correlation range of 3,000–15,000; film effectiveness uses a flat-plate correlation for shaped holes and
   extrapolates it to cylindrical showerhead holes; the film correlation assumes 30° injection while the modelled suction-side holes
   are inclined at 35–45° (the first feasible angle among 30°, 35°, 40° and 45° was used; the chosen angles are not published); rib enhancement (2.4) and the metal conductivity law are assumed. The sensitivities in
   [`design/sensitivity/`](design/sensitivity/) bound some of this: film effectiveness −30 % adds 46 K, cut-back
   effectiveness 0.7 → 0.5 adds 47 K, internal heat transfer −20 % adds 6 K. These sensitivities were computed on the 94-hole model (nominal 1,312 K, margin 45 K) and were not rerun for 91 holes; if the +46 K and +47 K deltas carry over, either film case alone uses the 40 K margin of the 91-hole design.
6. **The effect of removing three holes is a bound, not a result.** Going from 94 to 91 hole features is modelled with a
   smeared hole density: the two showerhead holes give +5.5 K peak metal temperature and −0.3 g/s coolant, the crossover hole
   0 K and −0.2 g/s (−0.5 g/s together). The local effect at the hub end was not resolved.

## Geometry review

7. **Wall minimum is not sourced to a standard.** The 0.457 mm floor used in the geometry review is the thinnest cast wall in one
   patent (US 5,296,308). A second patent (US 6,255,000) states that conventional casting could not reliably produce
   walls below 0.03 in (0.76 mm). The sampled trailing-edge lip minimum is 0.677 mm (designed 0.75 mm), so the lip assumes an
   advanced thin-wall casting process. The 0.40 mm bleed-slot height is an assumed minimum core thickness. Holes are assumed
   to be drilled or EDM-formed after casting.
8. **Wall values are sampled.** The wall probe uses 400 random points per skin face (150 per web) with a fixed seed; the
   minima are minima of the samples, not of the whole surface. Web minimum 0.848 mm against a 0.9 mm design value.
9. **Several reviews compare the solid with the intended feature geometry.** The hole-breakthrough, passage, connectivity and
   hole-spacing results compare the exported solid with the intended hole and passage geometry taken from the design
   data. They show that the solid contains the designed features, not that the design is correct; a shared error in that
   intended geometry would not be visible to them. Only the sampled-point, residual-metal, wall-thickness and slot reviews
   measure or classify the solid alone.
10. **The outlet-opening review is an indication only.** For the 55 outlets (51 film holes and 4 tip holes) it tests whether
    the hole axis crosses the outer surface and its end lies in air; it was not shown to reject a closed hole. Hole
    breakthrough itself is established by the residual-metal measurement.
11. **Not done:** flood-fill connectivity of the coolant volume; hole-to-hole interference; surface-intersection
    measurement of film-hole exit shapes. One hole (SS2 row #7) reaches its passage with a marginal inner end.
12. **SolidWorks `Check2` returns 2 for the imported file**, a result that has not been explained. The import itself is
    one body with a volume that agrees with the independent measurement. SolidWorks reports 1,551 faces against 1,542 in the STEP file (it splits
    some closed faces) and a bounding box about 1.3 mm wider in both x and y; neither difference was investigated.
13. **Mesh preparation is needed.** 26 faces smaller than 0.001 mm² remain, 20 of them at the junctions of the
    trailing-edge bleed-slot ducts with the cut-back. The ducts sit 0.03 mm off neighbouring faces. Defeaturing at about 0.01–0.02 mm is expected before meshing. An automatic
    small-face fixer made the solid invalid on an earlier model and was not used.
14. **Rib surfaces are approximations.** The current-design ribs are splines through at most 12 points of the original offset curves;
    total rib volume is 0.7–0.9 % below the faceted version, and metal inside the passages is unchanged within 0.1 %.
15. **Volume.** A default surface-integration volume is unreliable on this model (16,500.8 mm³ against 17,216.6 mm³
    from adaptive integration); only the adaptive value and the SolidWorks value are quoted. A periodic platform face carries one added
    edge (at x = 7 mm) so that SolidWorks reads the correct volume; the geometry is unchanged.
16. **The structural derivative is a convenience.** It removes holes, ribs, pins and the cut-back; their local effect is
    neither included nor estimated.

## Earlier-geometry analyses

17. The 2-D RANS and screening FEA in [`analysis_context/`](analysis_context/README.md) were run on earlier geometry (the second design,
    including its flared-shank refinement). They do not validate the current design. The FEA excludes holes, ribs and pins, uses assumed temperature-dependent
    moduli, treats the single crystal as isotropic, and does not model the fir-tree contact or evaluate fatigue.

## Evidence that can and cannot be re-checked

18. The CAD model is published as a file, not with the means to regenerate it. File identity can be compared with the hashes
    in `cad/MANIFEST.json`, and the wall-thickness measurement can be repeated with `scripts/wall_probe.py`. The other
    geometry-review results are recorded in `verification/results/`; the software that produced them is not published, so
    they cannot be re-run here. The cooling model, optimisation, RANS and FEA set-ups are also not published.

This repository has not undergone independent external review.

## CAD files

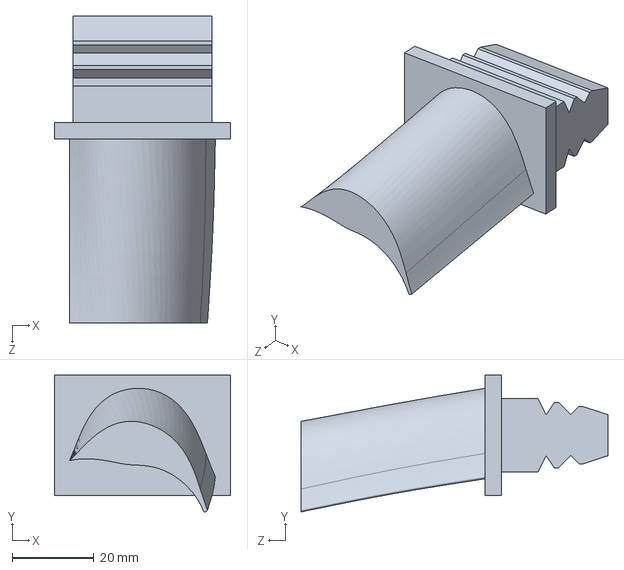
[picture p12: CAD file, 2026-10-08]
history/initial_design/GE_HPT_Blade_initial_design.SLDPRT
43.0 x 33.4 x 75.0 mm

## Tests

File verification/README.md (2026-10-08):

# Geometry review of the current CAD model

These are geometric reviews of the exported current CAD model. They were carried out on the file whose geometry section is
identical to the published STEP (see [`../cad/README.md`](../cad/README.md)). They show that the solid contains the designed
features and that the passages are connected as designed. They do not show that the design performs: there is no flow,
heat-transfer or structural result for the current design.

**Status words.** VERIFIED: measured on the exported solid. CALCULATED: from the project model or from the intended feature
geometry. ASSUMED: a stated assumption. NOT VERIFIED: not done.

## What was reviewed

| Review | What was examined | Result | Status | Limits | Record |
|---|---|---|---|---|---|
| Solid and topology | one solid, valid, one shell, face count | 1 solid, valid, 1,542 faces | VERIFIED | | `check_summary.json` |
| Volume | adaptive surface integration; independent mesh volume; SolidWorks import | 17,216.6 mm³; mesh 17,308 mm³ (+0.5 %); SolidWorks 17,218.5 mm³ | VERIFIED | a default surface-integration volume gives 16,500.8 mm³ on this model and is not used | `volume_measurement.json`, `solidworks_import.json` |
| Hole breakthrough | each hole's intended volume, shrunk 10 %, intersected with the solid; residual metal measured | all 91 holes: 0.0 mm³ residual metal, so every hole is cut through | VERIFIED | the hole volumes come from the intended hole geometry in the design data | `hole_residual_*.json` |
| Hole ends | a point 0.15 mm beyond each hole end must be outside the metal | all confirmed except SS2 row #7, whose inner end only touches cavity B1; it is accepted because its passage link and residual-metal result confirm it | VERIFIED, one marginal hole | | `check_summary.json` |
| Outlet openings | for the 55 outlets (51 film holes, 4 tip holes), the hole axis crosses the outer surface and one end lies in ambient air | 55 of 55 | indication only | geometric test of the intended hole; it was not shown to reject a closed hole; hole breakthrough itself is the residual-metal review | `film_breakout.json` |
| Connectivity | each feed, hole and passage link overlaps its intended passage; points sampled in the overlap are void | 133 intended links found; both feeds reach the root face; 49 passage pairs have no unintended overlap | CALCULATED on the intended geometry; samples confirmed on the solid | overlaps and isolation compare feature volumes; only the sampled points are classified on the solid; not a flood fill | `connectivity_*.json` |
| Passage interiors | 300 random points per passage must not be metal | 10 passages, 0 metal points | VERIFIED | sampled | `passage_void_*.json` |
| Trailing-edge discharge slots | 15 points along each of the 11 slots must be void | all 11 open from the pin cavity to the outside | VERIFIED | sampled point classification on the solid | `te_exit_path.json` |
| Wall thickness | shortest distance from sampled wall points to the opposite wall | skin minimum 0.677 mm (trailing edge), 0.91 mm (A1), 0.938 mm or more elsewhere; web minimum 0.848 mm | VERIFIED against a 0.457 mm screening floor | 400 samples per skin face, 150 per web; the floor is a patent value | `wall_probe.json` |
| Hole spacing | smallest edge-to-edge gap between neighbouring holes of a family | tip holes 0.72 mm, crossover holes 1.40 mm, jets 1.96 mm, showerhead 2.03 mm | CALCULATED on the intended geometry | not measured on the solid | `connectivity_A_B0_C_F_G.json` (`ligaments`) |
| Design agreement | counts and diameters of the intended holes (design file of 94 holes minus the three removed) | 16 / 20 / 27 / 12 / 12 / 4 = 91 holes; diameters as designed | CALCULATED (consistency with the design data) | not a measurement of the solid | `connectivity_A_B0_C_F_G.json` (`design_check`) |

The overall summary (`check_summary.json`) records every review stage as satisfied against the 0.457 mm wall floor, i.e. the
geometry review completed successfully. Against the 0.76 mm conventional-casting indicator the trailing-edge lip would not
qualify; that is the manufacturing assumption stated in [`../LIMITATIONS.md`](../LIMITATIONS.md).

## What was not reviewed

* Flood-fill connectivity of the whole coolant volume (links and samples were examined, not full voxel connectivity).
* Hole-to-hole interference beyond the spacing above.
* Exit shape and area of film holes (a surface-intersection measurement).
* Flow, pressure drop, heat transfer, temperature, stress or life on the current design (no CFD, CHT or FEA).
* Manufacturability, tolerance or casting yield.
* Why SolidWorks reports `Check2` = 2 for the imported file. The import is one body and the volume agrees; SolidWorks counts 1,551 faces against 1,542 and a bounding box about 1.3 mm wider in both x and y, which was not investigated.
* Independent review.

## About the records

The files in [`results/`](results/) are the recorded outputs of the review, with local file paths replaced by file names; no
other field was changed. Their `sha256` fields refer to the reviewed copy of the file (`4c14c283…`), whose geometry section
is identical to the published STEP.

## What can be re-checked from this repository

* **File identity:** the archive, STEP and geometry-section SHA-256 values, the face counts, bounding box and volumes in
  [`../cad/MANIFEST.json`](../cad/MANIFEST.json) can be compared with the unzipped file in any STEP-capable tool.
* **Wall thickness:** `python scripts/wall_probe.py <unzipped STEP>` repeats the sampled wall measurement (about ten minutes);
  repeated on the published STEP it gave identical values.
* **Everything else** in the table above is recorded in `results/`. The software that produced those records is not
  published, so those results cannot be re-run from this repository, and no claim is made that the CAD model can be
  regenerated here.

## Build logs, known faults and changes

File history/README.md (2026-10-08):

# History

The current design was reached through a small number of design stages. Only the initial design is kept as a file; the
others are described here for context.

| Design | What it was | What it taught |
|---|---|---|
| [Initial design](initial_design/README.md) (Aug 2026) | An earlier blade with two manifold bores and 32 passage legs, built in SolidWorks. Superseded; the file is kept | A passage network that is connected to itself is not a cooling circuit, and a cooling layout is only as good as the blade shape around it. Its outer shape was about 1.8–1.9 times as thick as intended and had no leading-edge radius |
| Second design (Oct 2026) | A new blade designed from the stage velocity triangles, with two root-fed circuits, film cooling and, after refinement, a flared shank and an explicit trailing-edge exit. Not published as a file | Features must be placed from the exact section at their own radius; a volume check alone does not show a blind hole, so the exported solid has to be examined directly |
| Previous design | The second design with the hole set reduced from 94 to 91 holes and its geometry examined on the exported solid. Not published as a file | Three hole geometries were unsound, found only because the exported solid was examined; faceted rib surfaces left 3,846 faces |
| **Current design** | The previous design with smooth rib surfaces: 1,542 faces, same holes, pins, slots and passages | The current CAD model, in [`../cad/`](../cad/README.md) |

## Earlier states of this repository

An earlier version of this repository, published on GitHub in August 2026, presented the initial design as its subject.
Its claims were geometric (passage connectivity, wall thickness, ligaments) and they remain true for that solid; they were
not claims about a working cooling system, and they are no longer the subject of this repository.

## Not kept

Intermediate CAD files and working notes from the development are not published. The decisions that came out of them are
in [`../design/decisions.md`](../design/decisions.md).
